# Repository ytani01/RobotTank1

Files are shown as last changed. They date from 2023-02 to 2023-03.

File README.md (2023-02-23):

# Robot Tank

Robot Tank Package

## setup

### スワップファイル拡張

``` shell
sudo vi /etc/dphys-swapfile
-----
CONF_SWAPSIZE=1024
-----
sudo service dphys-swapfile restart
```

### 

### mjpg-streamer

[mjpg-streamer](./docs/mjpg-streamer.md)

## Reference

* [Python: 自作ライブラリのパッケージングについて](https://blog.amedama.jp/entry/packaging-python)
* [setuptools —Pythonパッケージ作成](https://heavywatal.github.io/python/setuptools.html)

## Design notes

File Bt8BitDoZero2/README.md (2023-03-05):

# Bt8BitDoZero2 - 8BitDo zero 2

Bluetooth gamepad

## Setup

### Install

``` shell
pip install -U evdev click
pip install .
```

### 8BitDo zero 2

Power on: [B]+[start]

### Bluetooth pairing

``` shell
$ sudo bluetoothctl
[...]# power on
[...]# scan on
[...]# connect FF:FF:C1:21:B3:FB
[...]# pair FF:FF:C1:21:B3:FB
[...]# trust FF:FF:C1:21:B3:FB
[...]# quit
```

### Test

``` shell
$ ls /dev/input
(check a number of device file)

$ sudo apt install evtest
$ sudo evtest
:
... (BTN_NORTH) ...
... (BTN_SOUTH) ...
[Ctrl]-C

$ ./evdev-test1.py
devs: ['/dev/input/event0']
input_dev device /dev/input/event0, name "AB Shutter3       ", phys "B8:27:EB:73:30:CC"
---
Push buttons.. ([Ctrl]-C to end)
event at 1676375759.365823, code 04, type 04, val 589828
event at 1676375759.365823, code 307, type 01, val 01
event at 1676375759.365823, code 00, type 00, val 00
event at 1676375759.542115, code 04, type 04, val 589828
event at 1676375759.542115, code 307, type 01, val 00
event at 1676375759.542115, code 00, type 00, val 00
event at 1676375760.197109, code 04, type 04, val 589828
event at 1676375760.197109, code 307, type 01, val 01
event at 1676375760.197109, code 00, type 00, val 00
event at 1676375760.375814, code 04, type 04, val 589828
event at 1676375760.375814, code 307, type 01, val 00
event at 1676375760.375814, code 00, type 00, val 00
:
[Ctrl]-C
```

###

/etc/systemd/system/bluetooth.service.d/override.conf
``` text
:
ExecStart=/usr/libexec/bluetooth/bluetoothd --compat --noplugin=sap
ExecStartPost=/usr/bin/sdptool add SP
:
```

``` shell
sudo systemctl daemon-reload
sudo systemctl restart bluetooth.service
```

##

``` shell
python3 -m bt8bitdozero2 robottank 0
```

## Trouble Shooting

###

???
``` shell
sudo hciconfig hci0 down
sudo hciconfig hci0 up
sudo /etc/init.d/bluetooth restart
```

## Software Architecture

``` text
```

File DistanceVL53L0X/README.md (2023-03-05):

# VL53L0X

VL53L0X: TOF Distance Sensor

## Install

###

``` shell
sudo apt install i2c-tools
```

### Gadgetoid/VL53L0X-python.git

``` shell
THISDIR=`pwd`
TOPDIR='../../'

pushd $TOPDIR

git clone git@github.com:Gadgetoid/VL53L0X-python.git

cd VL53L0X-python
make

cp ./bin/vl53l0x*.so $VIRTUAL_ENV/bin
cp ./python/VL53L0X.py $THISDIR/distancevl53l0x
cp ./python/VL53L0X_example.py $THISDIR/distancevl53l0x

popd

cd distancevl53l0x
patch -b < VL53L0X.py-patch
patch -b < VL53L0X_example.py-patch
```

### Python Package

``` shell
pip install -U smbus2 click
pip install .
```

### sample

``` shell
python3 -m distancevl53l0x distance
```

## server

``` shell
python3 -m distancevl53l0x server
```

## Software Architecture

``` text
```

## References

- [Gadgetoid/VL53L0X-python](https://github.com/Gadgetoid/VL53L0X-python)

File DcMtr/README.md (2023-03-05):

# DC Motor

DC Motor package

## Install

``` shell
cd ~
python3 -m venv env1
cd ~/env1
. ./bin/activate

git clone git@github.com:ytani01/RobotTank1.git

cd ~/env1/RobotTank1
git clone git@github.com:ytani01/CuiLib.git
cd ~/env1/RobotTank1/CuiLib
pip install .

cd ~/env1/RobotTank1/CmdClientServer
pip install .

cd ~/env1/RobotTank1/DcMtr
pip install pigpio click
pip install .
```

## samples

### server
``` shell
python3 -m dcmtr server 17 18 13 12
```

### client

``` shell
./sample_dcmtr_client.py
```

## Software Architecture

``` text
+-------------+
| DcMtrClient |
+-------------+
|  CmdClient  |
+-------------+
       |
       | TCP/IP
       v
+--------- server
|  CmdServer    |
|---------------|
|  |   DcMtrN   |
|  |------------|
|  |   DcMtr    |
|  +------------|
+---------------+
```

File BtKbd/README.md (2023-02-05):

# BtKbd - Bluetooth Keyboard

Bluetooh Keyboard package

## Setup

### Bluetooth pairing

``` shell
$ sudo bluetoothctl
[...]# power on
[...]# scan on
[...]# connect FF:FF:C1:21:B3:FB
[...]# pair FF:FF:C1:21:B3:FB
[...]# trust FF:FF:C1:21:B3:FB
[...]# quit
```

### Test

``` shell
$ ls /dev/input/event*
(check a number of device file)

$ sudo evtest
:
... (KEY_ENTER) ...
... (KEY_VOLUMEUP) ...
[Ctrl]-C

$ ./evdev-test1.py
devs: ['/dev/input/event0']
input_dev device /dev/input/event0, name "AB Shutter3       ", phys "B8:27:EB:73:30:CC"
---
Push buttons.. ([Ctrl]-C to end)
event at 1555345539.513055, code 04, type 04, val 786665
event at 1555345539.513055, code 115, type 01, val 01
event at 1555345539.513055, code 00, type 00, val 00
event at 1555345539.625007, code 04, type 04, val 786665
event at 1555345539.625007, code 115, type 01, val 00
event at 1555345539.625007, code 00, type 00, val 00
event at 1555345540.749932, code 04, type 04, val 786665
event at 1555345540.749932, code 115, type 01, val 01
event at 1555345540.749932, code 00, type 00, val 00
event at 1555345540.899922, code 04, type 04, val 786665
event at 1555345540.899922, code 115, type 01, val 00
event at 1555345540.899922, code 00, type 00, val 00

:

[Ctrl]-C
```

## Software Architecture

``` text
```

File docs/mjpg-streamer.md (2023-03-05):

# mjpg-streamer

## Install

``` sh
cd $VIRTURAL_VENV
sudo apt install -y git cmake libjpeg-dev
git clone https://github.com/neuralassembly/mjpg-streamer.git
cd mjpg-streamer/mjpg-streamer-experimental
make
```

## camera test

``` sh
vcgencmd get_camera
:
raspistill -n -o pi-camera.jpg
:
```

## Usage

Web Server
``` sh
./mjpg_streamer -o "./output_http.so -w ./www -p 8080" -i "./input_raspicam.so -x 1920 -y 1080 -fps $FPS -q 10 -rot 180 -vs"
```

Save jpeg files
``` sh
mkdir $HOME/tmp/pics
./mjpg_streamer -o "./output_http.so -w ./www -p 8080" -o "output_file.so -f $HOME/tmp/pics -d 2000" -i "./input_raspicam.so -x 1920 -y 1080 -fps 30 -q 10 -rot 180"
```

## Reference

* [Raspberry PiでMJPG-Streamerを使って監視カメラを作ってみよう](https://ponkichi.blog/mjpg-streamer/)

* [「ラズパイのカメラ動画保存方法」MJPG-streamerから簡単に出来ます！](https://denkenmusic.com/%E3%80%8C%E3%83%A9%E3%82%BA%E3%83%91%E3%82%A4%E3%81%AE%E3%82%AB%E3%83%A1%E3%83%A9%E5%8B%95%E7%94%BB%E4%BF%9D%E5%AD%98%E6%96%B9%E6%B3%95%E3%80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)

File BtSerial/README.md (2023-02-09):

# BtSerial - Bluetooth Serial

Bluetooh Serial Server

## Setup

### Bluetooth pairing

#### 1. ペアリング待受け

``` shell
$ sudo bluetoothctl
[...]# 
```

#### 2. スマホからペアリング

#### 3. パスキーによる承認

``` shell
[...]#
Request confirmation
[agent] Confirm passkey 198156 (yes/no): yes
```

一旦コネクトした後に切れてよい

### bluetoothd 設定

/usr/lib/systemd/system/bluetooth.service
```
- ExecStart=/usr/libexec/bluetooth/bluetoothd
+ ExecStart=/usr/libexec/bluetooth/bluetoothd -C
+ ExecStartPost=/usr/bin/sdptool add SP
```

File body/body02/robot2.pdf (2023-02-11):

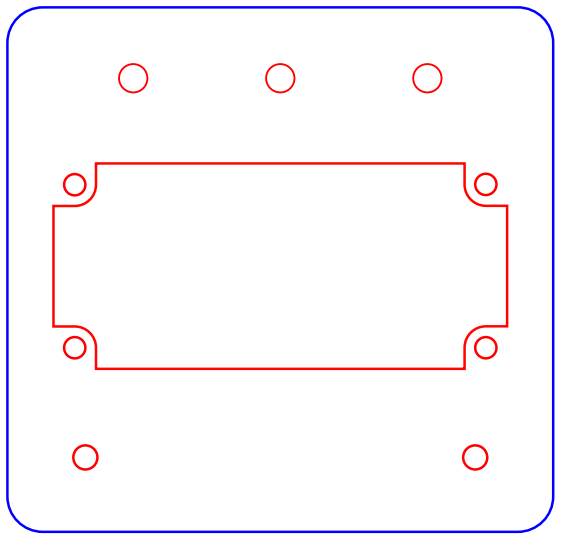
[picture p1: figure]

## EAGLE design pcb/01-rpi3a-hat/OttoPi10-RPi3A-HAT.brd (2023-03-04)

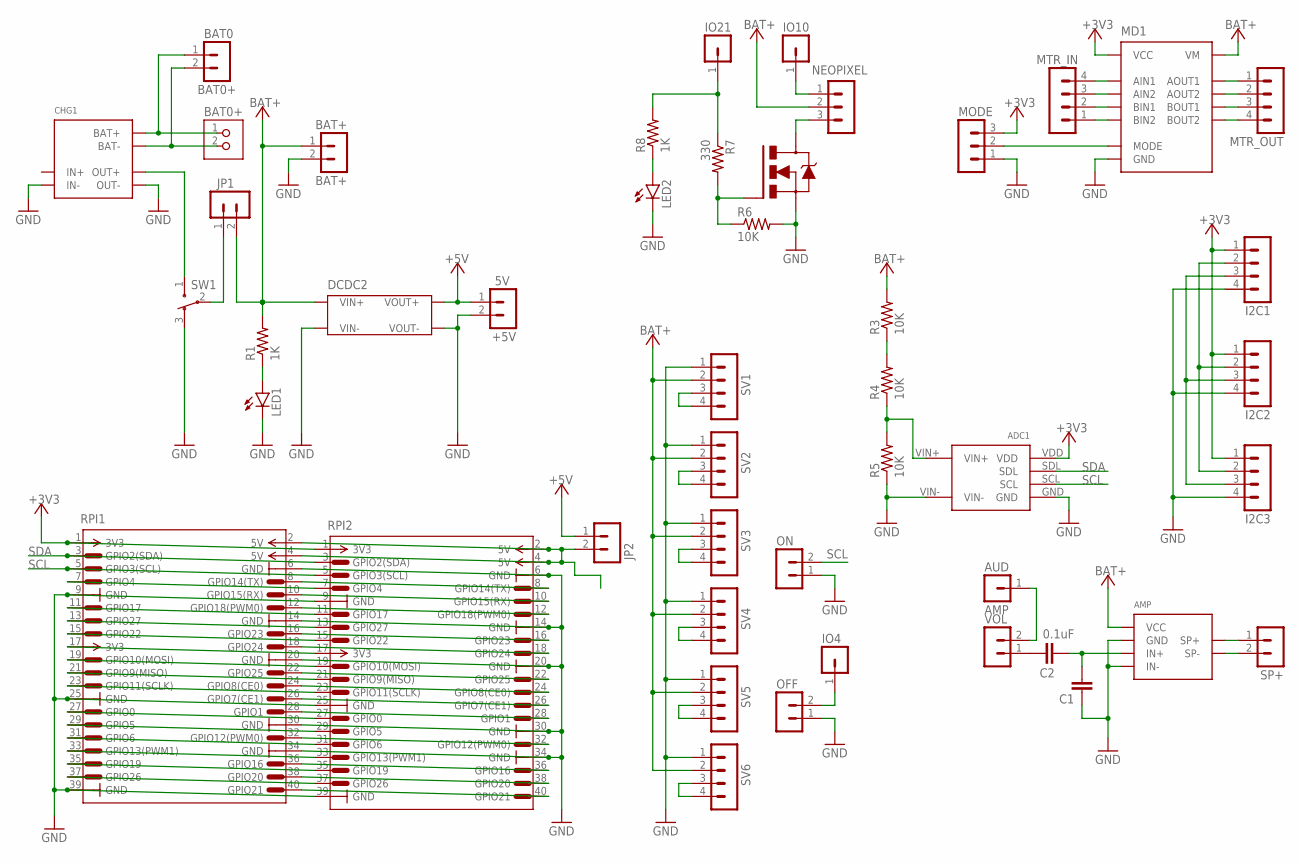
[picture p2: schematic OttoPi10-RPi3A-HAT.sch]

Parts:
+5V: 5V; PINHEAD-MA02-1
ADC1: MCP3425MOD
AMP: AMP; PAM8012MOD-A
AUD: AMP; PINHEAD-MA01-1
BAT0: BAT0+; PINHEAD-MA02-1
BAT0+: JST-PH2
BAT+: BAT+; PINHEAD-MA02-1
C1: C-EU025-024X044; C025-024X044
C2: 0.1uF; C025-024X044
CHG1: TP4056MOD1
DCDC2: DCDC-SX1308-MOD1
I2C1, I2C2, I2C3: PINHEAD-MA04-1
IO4, IO10, IO21: PINHEAD-MA01-1
JP1, JP2: PINHEAD-MA02-1
LED1, LED2: LED3MM
MD1: DRV8835MOD
MODE: PINHEAD-MA03-1
MTR_IN: PINHEAD-MA04-1
MTR_OUT: PINHEAD-MA04-1
NEOPIXEL: PINHEAD-MA03-1
OFF: PINHEAD-MA02-1
ON: PINHEAD-MA02-1
Q1: 2SK4017; MOSFET-1
R1, R8: 1K; 0204/7
R3, R4, R5, R6: 10K; 0204/7
R7: 330; 0204/7
RPI1, RPI2: RPI-PIN
SP+: PINHEAD-MA02-1
SV1, SV2, SV3, SV4, SV5, SV6: PINHEAD-MA04-1
SW1: SW3-1
VOL: PINHEAD-MA02-1

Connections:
+3V3: ADC1.VDD, I2C1.1, I2C2.1, I2C3.1, MD1.VCC, MODE.3, RPI1.1 (3V3), RPI2.1 (3V3)
+5V: +5V.1, DCDC2.VOUT+, JP2.1
+5V_RPI: JP2.2, RPI1.2 (5V), RPI1.4 (5V), RPI2.2 (5V), RPI2.4 (5V)
AIN1: MD1.AIN1, MTR_IN.4
AIN2: MD1.AIN2, MTR_IN.3
AOUT1: MD1.AOUT1, MTR_OUT.1
AOUT2: MD1.AOUT2, MTR_OUT.2
AUDIO0: AUD.1, VOL.2
AUDIO1: AMP.IN+, C1.2, C2.1
BAT+: AMP.V+ (VCC), BAT+.1, DCDC2.VIN+, JP1.2, MD1.VM, NEOPIXEL.2, R1.2, R3.2, SV1.2, SV2.2, SV3.2, SV4.2, SV5.2, SV6.2
BAT+0: BAT0.1, BAT0+.1, CHG1.BAT+
BAT+1: CHG1.OUT+, SW1.1
BAT+2: JP1.1, SW1.2
BAT-0: BAT0.2, BAT0+.2, CHG1.BAT-
BIN1: MD1.BIN1, MTR_IN.2
BIN2: MD1.BIN2, MTR_IN.1
BOUT1: MD1.BOUT1, MTR_OUT.3
BOUT2: MD1.BOUT2, MTR_OUT.4
GND: +5V.2, ADC1.GND, ADC1.VIN-, AMP.GND, AMP.IN-, BAT+.2, C1.1, CHG1.IN-, CHG1.OUT-, DCDC2.VIN-, DCDC2.VOUT-, I2C1.4, I2C2.4, I2C3.4, LED1.K (C), LED2.K (C), MD1.GND, MODE.1, OFF.1, ON.1, Q1.S, R5.1, R6.2, RPI1.6 (GND), RPI1.9 (GND), RPI1.14 (GND), RPI1.20 (GND), RPI1.25 (GND), RPI1.30 (GND), RPI1.34 (GND), RPI1.39 (GND), RPI2.6 (GND), RPI2.9 (GND), RPI2.14 (GND), RPI2.20 (GND), RPI2.25 (GND), RPI2.30 (GND), RPI2.34 (GND), RPI2.39 (GND), SV1.1, SV2.1, SV3.1, SV4.1, SV5.1, SV6.1, SW1.3
GPIO10: RPI1.17 (3V3), RPI2.17 (3V3)
MODE: MD1.MODE, MODE.2
unnamed: Q1.G, R6.1, R7.2
unnamed: NEOPIXEL.3, Q1.D
unnamed: LED1.A, R1.1
unnamed: IO21.1, R7.1, R8.2
unnamed: RPI1.7 (GPIO4), RPI2.7 (GPIO4)
unnamed: IO10.1, NEOPIXEL.1
unnamed: RPI1.11 (GPIO17), RPI2.11 (GPIO17)
unnamed: RPI1.13 (GPIO27), RPI2.13 (GPIO27)
unnamed: RPI1.15 (GPIO22), RPI2.15 (GPIO22)
unnamed: RPI1.23 (GPIO11(SCLK)), RPI2.23 (GPIO11(SCLK))
unnamed: RPI1.19 (GPIO10(MOSI)), RPI2.19 (GPIO10(MOSI))
unnamed: RPI1.21 (GPIO9(MISO)), RPI2.21 (GPIO9(MISO))
unnamed: C2.2, VOL.1
unnamed: LED2.A, R8.1
unnamed: RPI1.8 (GPIO14(TX)), RPI2.8 (GPIO14(TX))
unnamed: RPI1.10 (GPIO15(RX)), RPI2.10 (GPIO15(RX))
unnamed: RPI1.12 (GPIO18(PWM0)), RPI2.12 (GPIO18(PWM0))
unnamed: RPI1.16 (GPIO23), RPI2.16 (GPIO23)
unnamed: RPI1.18 (GPIO24), RPI2.18 (GPIO24)
unnamed: RPI1.22 (GPIO25), RPI2.22 (GPIO25)
unnamed: IO4.1, OFF.2
unnamed: R3.1, R4.2
unnamed: ADC1.VIN+, R4.1, R5.2
unnamed: RPI1.24 (GPIO8(CE0)), RPI2.24 (GPIO8(CE0))
unnamed: RPI1.26 (GPIO7(CE1)), RPI2.26 (GPIO7(CE1))
unnamed: RPI1.27 (GPIO0), RPI2.27 (GPIO0)
unnamed: RPI1.28 (GPIO1), RPI2.28 (GPIO1)
unnamed: RPI1.29 (GPIO5), RPI2.29 (GPIO5)
unnamed: RPI1.31 (GPIO6), RPI2.31 (GPIO6)
unnamed: RPI1.32 (GPIO12(PWM0)), RPI2.32 (GPIO12(PWM0))
unnamed: RPI1.33 (GPIO13(PWM1)), RPI2.33 (GPIO13(PWM1))
unnamed: RPI1.35 (GPIO19), RPI2.35 (GPIO19)
unnamed: RPI1.36 (GPIO16), RPI2.36 (GPIO16)
unnamed: RPI1.37 (GPIO26), RPI2.37 (GPIO26)
unnamed: RPI1.38 (GPIO20), RPI2.38 (GPIO20)
unnamed: RPI1.40 (GPIO21), RPI2.40 (GPIO21)
unnamed: SV2.3, SV2.4
unnamed: SV3.3, SV3.4
unnamed: SV4.3, SV4.4
unnamed: SV1.3, SV1.4
unnamed: SV5.3, SV5.4
unnamed: SV6.3, SV6.4
SCL: ADC1.SCL, I2C1.3, I2C2.3, I2C3.3, ON.2, RPI1.5 (GPIO3(SCL)), RPI2.5 (GPIO3(SCL))
SDA: ADC1.SDL, I2C1.2, I2C2.2, I2C3.2, RPI1.3 (GPIO2(SDA)), RPI2.3 (GPIO2(SDA))
SP+: AMP.SP+@1 (SP+), SP+.1
SP-: AMP.SP-@1 (SP-), SP+.2

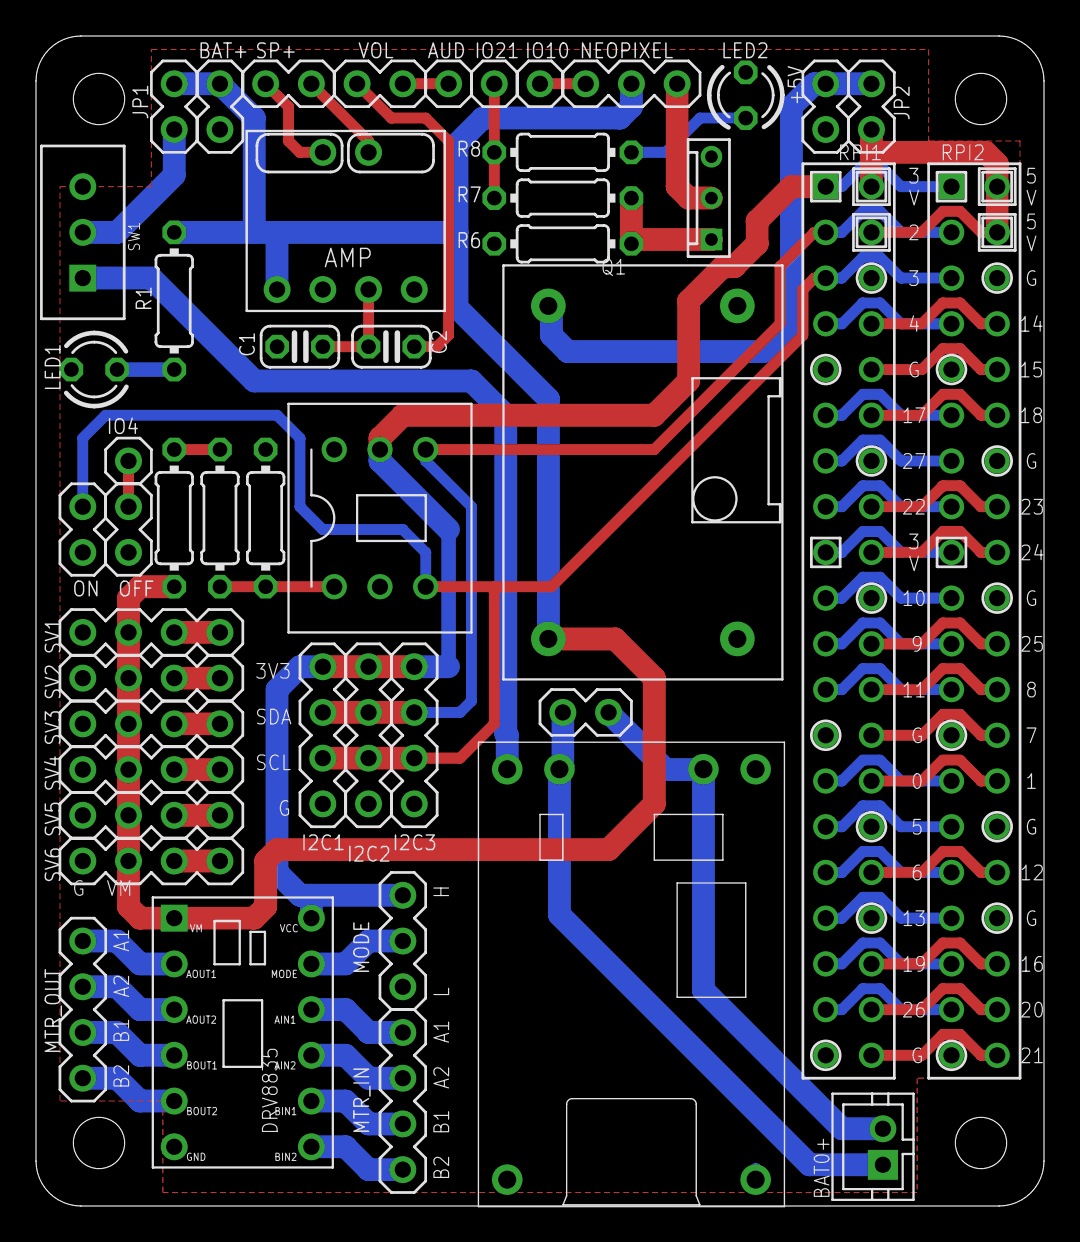
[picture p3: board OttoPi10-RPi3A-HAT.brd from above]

Board: 2 copper layers, 56.0 x 65.0 mm, 47 parts (0 on the bottom side), 67 nets.

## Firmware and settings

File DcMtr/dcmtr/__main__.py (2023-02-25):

#
# Copyright (c) 2023 Yoichi Tanibayashi
#
import click
from . import __prog_name__, __version__, __author__
from . import server
from . import get_logger


@click.group(invoke_without_command=True,
             context_settings=dict(help_option_names=['-h', '--help']),
             help=" by " + __author__)
@click.option('--opt', '-o0', 'opt', type=str, default=None, help='opt1')
@click.option('--debug', '-d', 'debug', is_flag=True, default=False,
              help='debug flag')
@click.version_option(version=__version__)
@click.pass_context
def cli(ctx, opt, debug):
    """ command group """
    __log = get_logger(__name__, debug)
    __log.debug('opt=%s', opt)

    ctx.obj = {'opt': opt, 'debug': debug}

    subcmd = ctx.invoked_subcommand
    __log.debug('subcmd=%s', subcmd)

    if not subcmd:
        print(ctx.get_help())


cli.add_command(server)


if __name__ == '__main__':
    cli(prog_name=__prog_name__)

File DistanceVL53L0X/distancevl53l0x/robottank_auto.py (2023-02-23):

#!/usr/bin/env python3
#
# Copyright (c) 2023 Yoichi Tanibayashi
#
# -*- coding: utf-8 -*-
#
import click
import time
# import datetime
import random
import threading
from enum import Enum
from cmdclientserver import CmdClient
from bt8bitdozero2 import Bt8BitDoZero2, Bt8BitDoZero2N
from . import DistanceClient
from .my_logger import get_logger


class Direction(Enum):
    """ Direction """
    STOP = 0
    FORWARD = 1
    BACKWARD = 2
    LEFT = 3
    RIGHT = 4
    NULL = -1


class SensorWatcher(threading.Thread):
    """ Sensor Watcher  """

    DEF_DISTANCE_NEAR = 120
    DISTANCE_TOO_NEAR = 50
    DISTANCE_FAR = 600
    DISTANCE_MAX = 8190

    def __init__(self, dc_mtr, base_speed, distance_client, debug=False):
        """
        Parameters
        ----------
        dc_mtr: CmdClient
        base_speed: int
        distance_client: DistanceClient
        """
        self._dbg = debug
        __class__.__log = get_logger(__class__.__name__, self._dbg)
        self.__log.debug('base_speed=%s', base_speed)

        self._dc_mtr = dc_mtr
        self._base_speed = base_speed
        self._d_clnt = distance_client

        self._active = False
        self._auto = False
        self._distance_near = self.DEF_DISTANCE_NEAR

        super().__init__(daemon=True)

    def end(self):
        self.__log.debug('')
        self._active = False
        self.join()
        self.__log.debug('END')

    def is_auto(self):
        return self._auto

    def toggle_auto(self):
        if self._auto:
            self.auto_off()
        else:
            self.auto_on()

    def auto_on(self):
        self._auto = True

    def auto_off(self):
        self._auto = False

    def run(self):
        self.__log.debug('')

        self._active = True

        near_count = 0

        while self._active:
            speed = self._base_speed

            distance = self._d_clnt.get_distance()
            if distance is None:
                self._dc_mtr.call('CLEAR')
                self._dc_mtr.call('SPEED 0 0')
                time.sleep(1)
                continue

            if distance < 0.0:
                self._dc_mtr.call('CLEAR')
                self._dc_mtr.call('SPEED 0 0')
                time.sleep(1)
                continue

            if distance >= self.DISTANCE_MAX:
                self.__log.warning('distance=%s??', distance)
                time.sleep(0.5)
                continue

            self.__log.debug('distance=%s', distance)

            if not self.is_auto():
                time.sleep(.5)
                continue

            if (distance < self._distance_near * 1.1 or
                distance > self.DISTANCE_FAR):

                self.__log.info('near_count=%s,%smm(%s,%s)!!',
                                near_count, int(distance),
                                self._distance_near, self.DISTANCE_FAR)

                if (distance >= self._distance_near and
                    distance <= self.DISTANCE_FAR):

                    time.sleep(0.1)
                    continue

                self._dc_mtr.call('CLEAR')

                # stop
                self._dc_mtr.call('SPEED 0 0')
                delay1 = 0.2
                self._dc_mtr.call('DELAY %s' % (delay1))

                if near_count < 2:
                    near_count += 1
                    time.sleep(delay1)
                    continue

                near_count = 0

                # back
                self._dc_mtr.call('SPEED %s %s' % (-speed, -speed))

                delay2 = 0.3 + random.random() / 2
                self._dc_mtr.call('DELAY %s' % (delay2))

                # turn
                turn_speed = int(speed / 2)
                if random.random() >= 0.4:
                    self._dc_mtr.call(
                        'SPEED %s %s' % (turn_speed, -turn_speed))
                else:
                    self._dc_mtr.call(
                        'SPEED %s %s' % (-turn_speed, turn_speed))

                delay3 = 0.5 + random.random() * 1.5
                self._dc_mtr.call('DELAY %s' % (delay3))

                time.sleep(delay1 + delay2 + delay3)
                # time.sleep(delay1 + delay2)

            near_count = 0
            time.sleep(0.001)

        self._dc_mtr.call('STOP')


class RobotTankAuto:
    """ Robot Tank Auto Pilot """

    SPEED_MAX = 100
    DEF_BASE_SPEED = 70

    def __init__(self, devs=[], offset=0.0, interval=0.0,
                 dc_mtr=None, distance_client=None,
                 debug=False):
        """
        Parameters
        ----------
        offset: float
        interval: float
        dc_mtr: DcMtrclient
        distance_client: DistanceClient
        devs: list()
        """
        self._dbg = debug
        __class__.__log = get_logger(__class__.__name__, self._dbg)
        self.__log.debug('devs=%s, offset=%s, interval=%s',
                         devs, offset, interval)

        self._devs = devs
        self._offset = offset
        self._interval = interval
        self._dc_mtr = dc_mtr
        self._d_clnt = distance_client

        self._dir = Direction.LEFT
        self._base_speed = self.DEF_BASE_SPEED
        self._auto = False
        self._prev_auto = False

        self._watcher = SensorWatcher(
            self._dc_mtr, self._base_speed, self._d_clnt, debug=self._dbg)

        self._bt8bitdozero2 = Bt8BitDoZero2N(
            self._devs, self.btn_cb, debug=self._dbg)

    def main(self):
        self.__log.debug('')

        self._watcher.start()

        self._bt8bitdozero2.start()

        if self._interval <= 0.0:
            self._interval = 0.01
            self.__log.debug('interval=%s', self._interval)

        try:
            while True:
                if not self.is_auto():
                    self.__log.debug('auto=%s', self._auto)
                    time.sleep(1)
                    continue

                cmdline = 'SPEED 0 0'

                if self._dir == Direction.LEFT:
                    cmdline = 'SPEED %s %s' % (
                        int(self._base_speed / 3), self._base_speed)
                    self._dir = Direction.RIGHT
                else:
                    cmdline = 'SPEED %s %s' % (
                        self._base_speed, int(self._base_speed / 3))
                    self._dir = Direction.LEFT

                self._dc_mtr.call(cmdline)

                time.sleep(.7 + random.random())

        except KeyboardInterrupt as e:
            self.__log.warning('%s:%s', type(e).__name__, e)

        except Exception as e:
            self.__log.error('%s:%s', type(e).__name__, e)

        self._dc_mtr.call('CLEAR')
        self._dc_mtr.call('SPEED 0 0')
        self._watcher.end()

    def btn_cb(self, dev, evtype, code, val):
        """  """
        self.__log.debug('')

        # !! code_strがlistのこともある !!
        code_str = Bt8BitDoZero2.keycode2str(evtype, code)
        val_str = Bt8BitDoZero2.keyval2str(evtype, val)
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

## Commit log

2023-01-29 UPD: DcMtr/
    [entry_points.cfg]
2023-02-01 ADD: AbShutter/
    [entry_points.cfg]
2023-02-02 UPD: rename "dc_mtr" to "dcmtr"
    [entry_points.cfg]
2023-02-09 ADD: BtSerial/
    [entry_points.cfg]
2023-02-14 ADD: Bt8BitDoZero2/
    [entry_points.cfg]
2023-02-15 ADD: DistanceVL530X
    [entry_points.cfg]
2023-02-19 ADD: TcpClientServer/
    [entry_points.cfg]
2023-02-19 ADD: CmdClientServer/
    [entry_points.cfg]
2023-02-23 ADD: Bt8BitDoZero2/sample1.py
2023-02-25 UPD: buttons
2023-03-02 UPD: crontab.sample: slack-ipaddr.sh
2023-03-04 UPD: pcb/
    [OttoPi10-RPi3A-HAT.brd, OttoPi10-RPi3A-HAT.sch]
